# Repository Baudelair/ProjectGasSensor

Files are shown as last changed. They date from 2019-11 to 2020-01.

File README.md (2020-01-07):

# ProjectGasSensor

Durant les différents travaux pratiques que nous avons eu, nous avons pu créer un capteur de gaz connecté. Nous avons tout d'abord réalisé un capteur de gaz depuis le début dans une salle blanche pour ensuite la connecté à une board Arduino. Dans ce repository, vous pourrez avoir accés au datasheet du capteur de gaz mais aussi le PCB conçu pour être un shield Arduino Uno.
Ainsi, on se retrouve avec un détecteur de fumée connecté à LoRa et qui a la capacité de sonné en cas de détection de fumée.

## Partie Kicad 

### Conception du traitement du signal du capteur de gaz

Nous avons utilisé un montage suggéré par Monsieur Noullet (https://noullet-gei.gitlab.io/iss_analog/) dont le but du filtre passe-bande est d'extraire toute l'information utile du capteur et atténuer la composante de bruit.
Vous pouvez voir ci-dessous le schéma électrique de ce filtrage ainsi que des autres composants utilisés sur le shield.

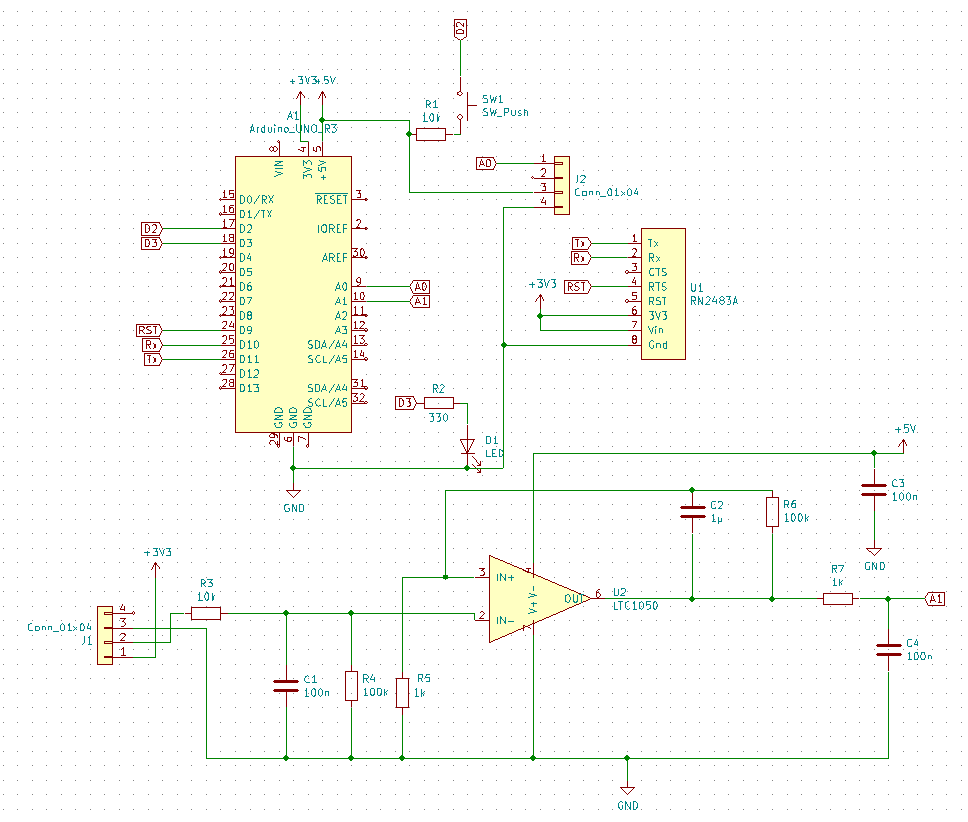
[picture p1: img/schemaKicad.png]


### Réalisation du shield Arduino Uno

Dans la partie que nous avons désiré réaliser, nous avons décidé de créer un shield avec comme composant notre capteur de gaz avec toute sa partie traîtement du signal ainsi qu'un buzzer et d'une LED. Tout ce système est relié à un programme Arduino décrit ci-dessous. Nous avons aussi souhaité rajouter un module LoRa qui permet de se connecter à l'interface IoT "The Things Network". On se retrouve ainsi avec ce shield (sous View3D de Kicad) :

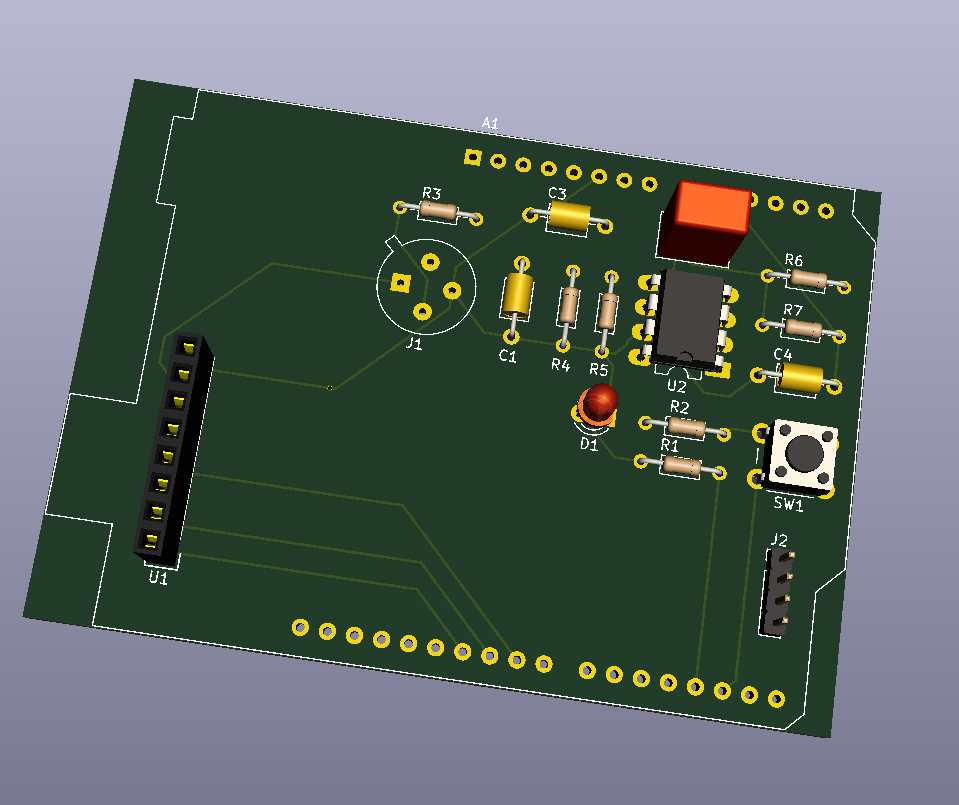
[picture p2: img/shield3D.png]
shield3D


On peut distinguer sur la partie haute à droite, le traitements du signal avec J1 le capteur de gaz. U1 correspond au connecteur pour le module LoRa et J2 correspond à une connectique pour le capteur de gaz de type Groove.

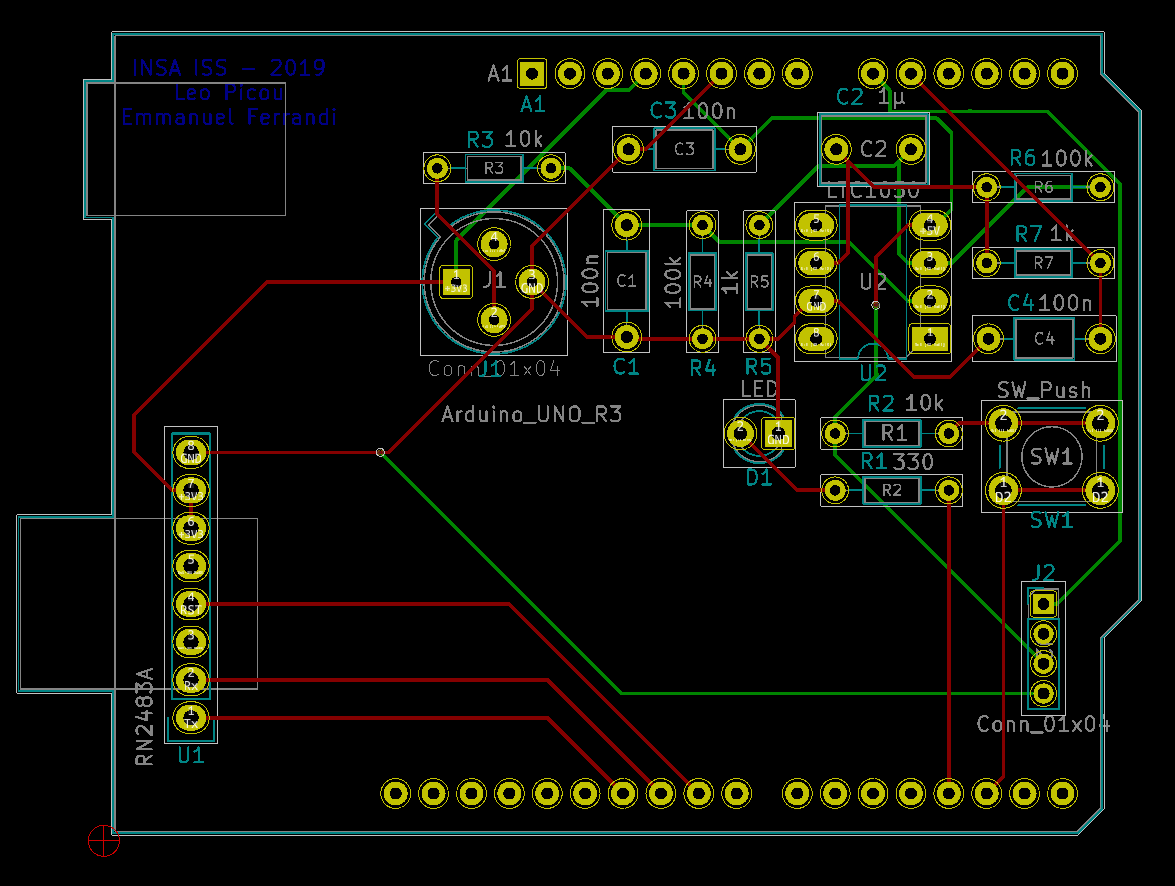
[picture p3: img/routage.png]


## Partie code 

Dans un premier temps, pour le bon fonctionnement de tous les composants, une étape de calibration est nécessaire. Pour communiquer avec le réseau The Thing Network, il faut entrer des valeurs de clé comme la devAddr (adresse de notre réseau), nwkSKey (clé pour notre réseau) et appSKey (clé de l'application de notre réseau). Pour le capteur de gaz, on doit configurer R0 afin de calibrer le capteur à l'atmosphère ambiante et ainsi détecter la présence d'un gaz après.
Ensuite, viens l'étape où l'on récupére les données du capteur de gaz et on les envoie grâce à LoRa sur notre réseau. Par la suite, il est possible d'utiliser ces informations comme bon nous semble. 

## Elargissement

Pour améliorer notre projet, il est possible de faire une application Androïd qui pourrait avertir l'utilisateur de la présence du fumée au sein de sa maison. Si jamais il n'y pas de réponse de sa part, les pompiers pourraient être averti pour éviter tout risque. 
Cette architecture peut aussi être utilisé dans différents domaines comme la détection de place de parking, le détecteur de présence... Il suffit juste de changer le capteur de gaz par un autre (ainsi que modifier la partie traitement du signal).

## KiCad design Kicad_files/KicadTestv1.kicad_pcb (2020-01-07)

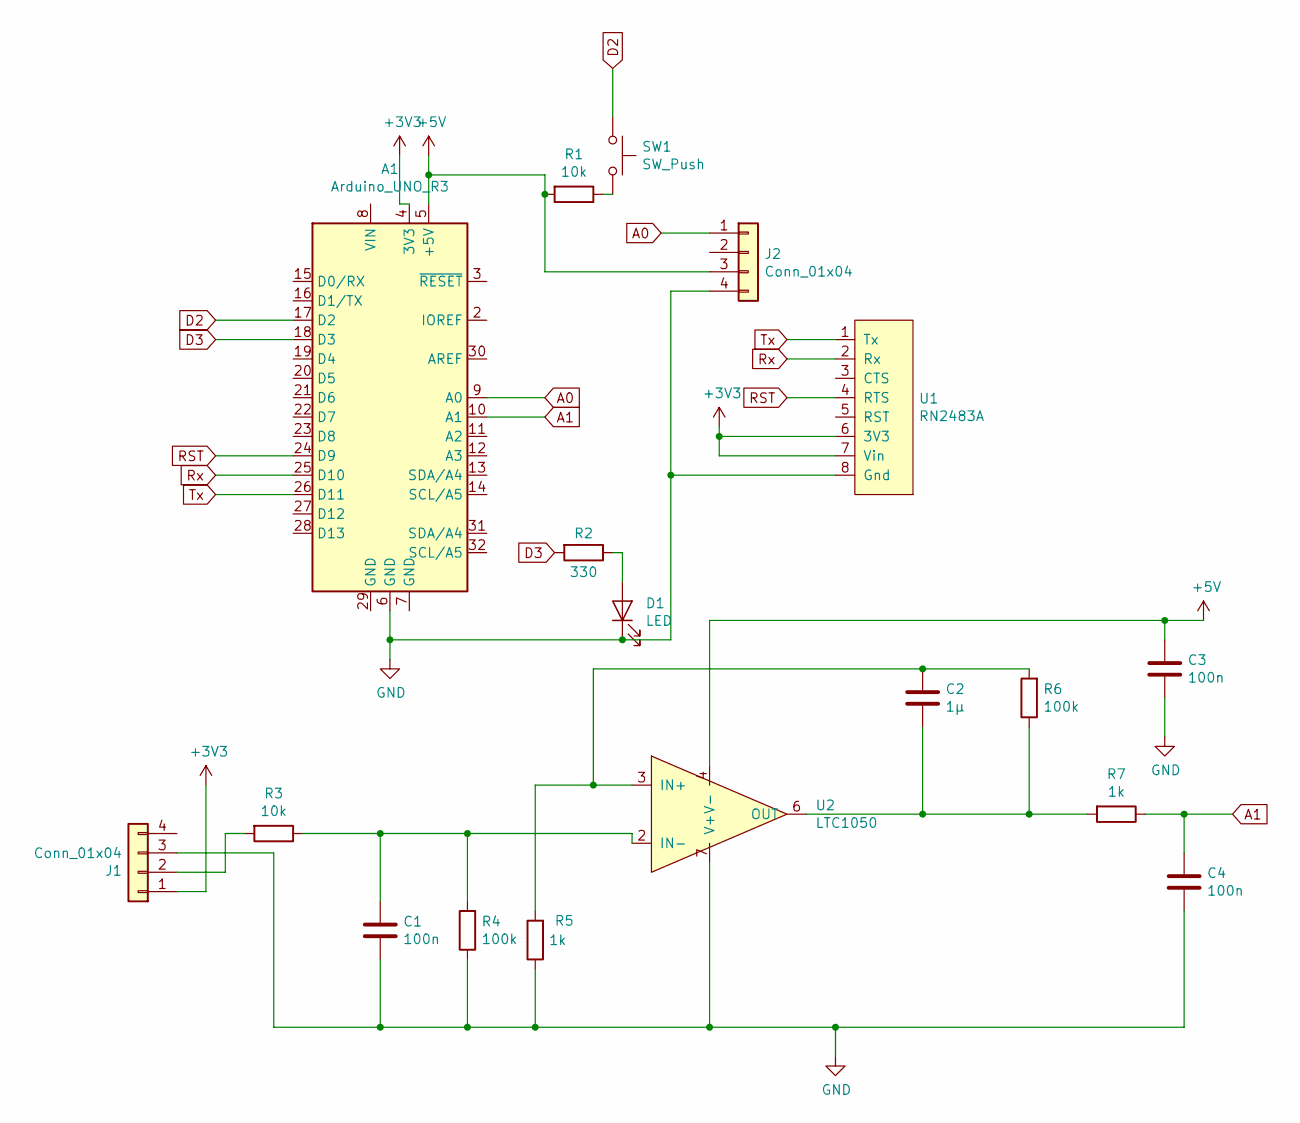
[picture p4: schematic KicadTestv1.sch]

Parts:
A1: Arduino_UNO_R3
C1, C3, C4: 100n; C_Axial_L3.8mm_D2.6mm_P7.50mm_Horizontal
C2: 1µ; C_Rect_L7.0mm_W4.5mm_P5.00mm
D1: LED; LED_D3.0mm
J1: Conn_01x04; TO-5-4_1
J2: Conn_01x04; PinHeader_1x04_P2.00mm_Vertical
R1, R3: 10k; R_Axial_DIN0204_L3.6mm_D1.6mm_P7.62mm_Horizontal
R2: 330; R_Axial_DIN0204_L3.6mm_D1.6mm_P7.62mm_Horizontal
R4, R6: 100k; R_Axial_DIN0204_L3.6mm_D1.6mm_P7.62mm_Horizontal
R5, R7: 1k; R_Axial_DIN0204_L3.6mm_D1.6mm_P7.62mm_Horizontal
SW1: SW_Push; SW_PUSH_6mm
U1: RN2483A; Socket_Strip_Arduino_1x08
U2: LTC1050; DIP-8_W7.62mm_LongPads

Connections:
+3V3: A1.4 (3V3), J1.1, U1.6 (3V3), U1.7 (Vin)
+5V: A1.5 (+5V), C3.1, J2.3, R1.2, U2.4 (V-)
A0: A1.9 (A0), J2.1
A1: A1.10 (A1), C4.1, R7.1
D2: A1.17 (D2), SW1.1
D3: A1.18 (D3), R2.2
GND: A1.6 (GND), C1.2, C3.2, C4.2, D1.1 (K), J1.3, J2.4, R4.1, R5.1, U1.8 (Gnd), U2.7 (V+)
unnamed: C1.1, R3.1, R4.2, U2.2 (IN-)
unnamed: C2.1, R5.2, R6.2, U2.3 (IN+)
unnamed: C2.2, R6.1, R7.2, U2.6 (OUT)
unnamed: D1.2 (A), R2.1
unnamed: J1.2, R3.2
unnamed: R1.1, SW1.2
RST: A1.24 (D9), U1.4 (RTS)
Rx: A1.25 (D10), U1.2 (Rx)
Tx: A1.26 (D11), U1.1 (Tx)

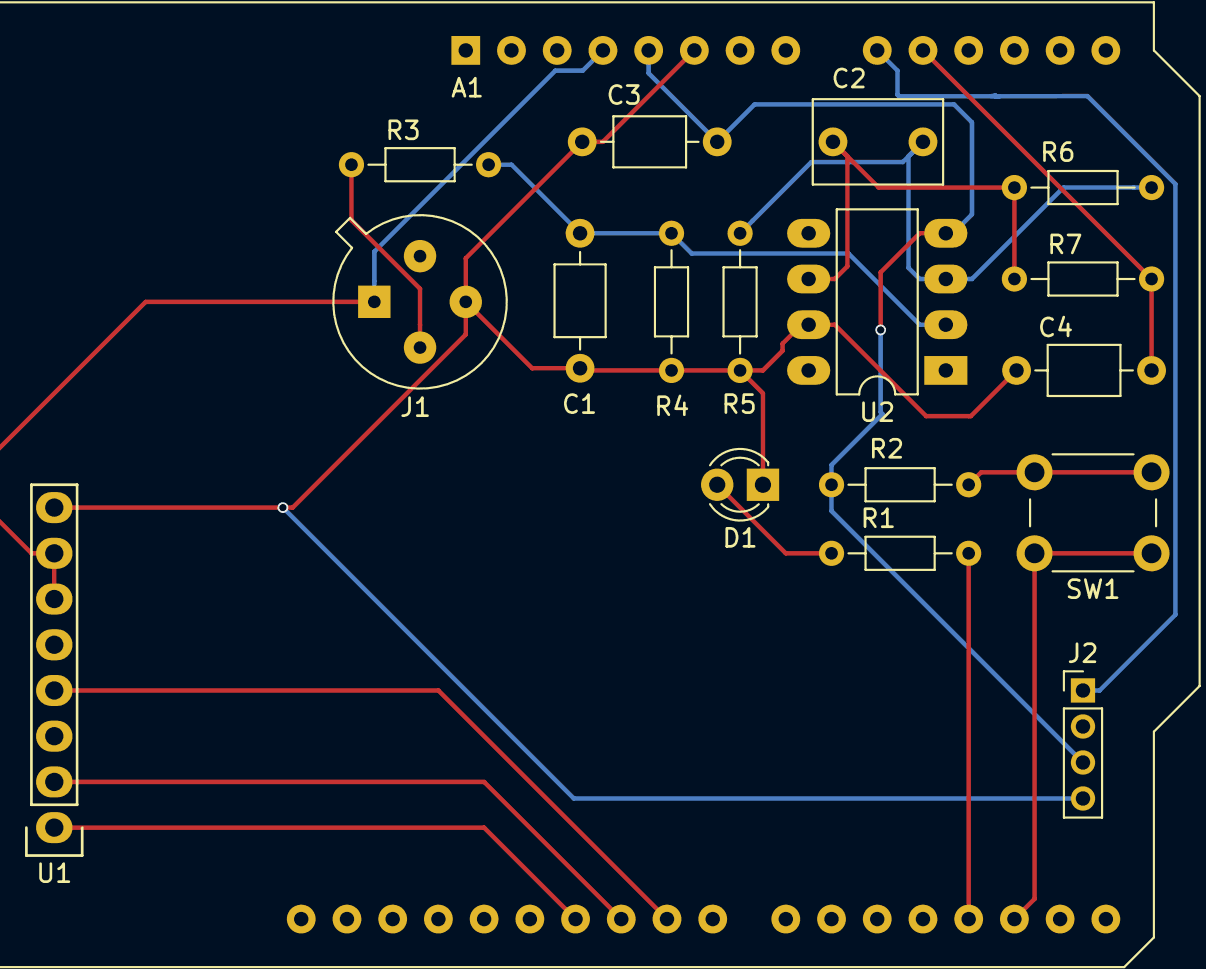
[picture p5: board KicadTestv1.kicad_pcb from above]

Board: 2 copper layers, 18 parts (0 on the bottom side), 16 nets.

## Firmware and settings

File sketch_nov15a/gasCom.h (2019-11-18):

float gasMesure(float R0){
  float sensor_volt;
  float RS_gas; // Get value of RS in a GAS
  float ratio; // Get ratio RS_GAS/RS_air
  
  float sensorValue = analogRead(A0);
  
  sensor_volt= sensorValue/1024*5.0;
  RS_gas = (5.0-sensor_volt)/sensor_volt; // omit * RL

        /*-Replace the name "R0" with the value of R0 in the demo of First Test -*/
  ratio = RS_gas/R0;  // ratio = RS/R0
        /*-----------------------------------------------------------------------*/

  Serial.print("sensor_volt = ");
  Serial.println(sensor_volt);
  Serial.print("RS_ratio = ");
  Serial.println(RS_gas);
  Serial.print("Rs/R0 = ");
  Serial.println(ratio);
  Serial.print("\n\n");

  return ratio;
   
}

float gasCalibration(){
  float sensor_volt = 0;
    float RS_air = 0 ; //  Get the value of RS via in a clear air
    float R0 = 0;  // Get the value of R0 via in Alcohol
    float sensorValue = 0;

    /*--- Get a average data by testing 100 times ---*/
    for(int x = 0 ; x < 100 ; x++)
    {
        sensorValue = sensorValue + analogRead(A0);
    }
    sensorValue = sensorValue/100.0;
    /*-----------------------------------------------*/

    sensor_volt = sensorValue/1024*5.0;
    RS_air = (5.0-sensor_volt)/sensor_volt; // omit *RL
    R0 = RS_air/60.0; // The ratio of RS/R0 is 60 in a clear air from Graph (Found using WebPlotDigitizer)

    Serial.print("sensor_volt = ");
    Serial.print(sensor_volt);
    Serial.println("V");

    Serial.print("R0 = ");
    Serial.println(R0);
    return R0;
}

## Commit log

2019-11-25 Mise en place Kicad
    [KicadTestv1.kicad_pcb, KicadTestv1.sch]
2019-12-03 clean arduino sketchs
2019-12-03 moved kicad files
    [KicadTestv1.kicad_pcb, KicadTestv1.sch]
2019-12-04 Ajout Lib pour RN2483 & Modificition Empreinte et cablage
    [KicadTestv1.kicad_pcb, KicadTestv1.sch]
2019-12-11 Modification empreinte et ajout circuit capteur AIME + faire routage
    [KicadTestv1.kicad_pcb, KicadTestv1.sch]
2019-12-11 Debut cablages
    [KicadTestv1.kicad_pcb, KicadTestv1.sch]
2019-12-13 Cablage fait + verifier prochain commit si le module LoRa rentre
    [KicadTestv1.kicad_pcb, KicadTestv1.sch]
2020-01-06 Mise en beauté de Kicad
    [KicadTestv1.kicad_pcb]
2020-01-07 Ajout de README + dossier pour image du README
    [KicadTestv1.kicad_pcb, KicadTestv1.sch]
